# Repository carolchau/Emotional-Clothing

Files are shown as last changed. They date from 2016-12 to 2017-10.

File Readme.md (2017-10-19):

[emotions table]: http://i.imgur.com/i2DKPvF.png "Emotions Table"
[materials]: http://i.imgur.com/itTRcLl.jpg "Materials"
[wave shield]: http://i.imgur.com/GLxlWJJ.jpg "Wave Shield"
[rgb sensor]: http://i.imgur.com/IK1A827.jpg "RGB Sensor"
[lcd]: http://i.imgur.com/u8NLPdG.jpg "LCD"
[button]: http://i.imgur.com/u8NLPdG.jpg "Button"
[finished]: http://i.imgur.com/IV4h7Ai.jpg "Final Product"
[video]: http://i.imgur.com/NeDSLdI.jpg "Video"

# Emotional Clothing

Have you ever looked at someone's shirt and wondered, "What would that shirt sound like?". Of course you have.
Well now you can with this product. By simply hovering this device over someone's shirt or any article of clothing, you too can listen to the hidden melodies in our clothing.

We may not realize it but people often associate certain colors with specific feelings as numerous studies have shown. It's also no secret that music has incredible impact on our current state of emotions as well.
So why not combine these two factors to enhance the vibes they give off?

The colors and songs played will target emitting various emotions such as:

emotions table

## How it works

Every shirt will give off a specific HSL value. Based on that value, the device will play a specific song that will give off an atmospheric mood similar to what the color gives off. And LCD Screen will display the Song & Artist, the Mood, and the corresponding HSL value.

The HSL value that the sensor picks up will be classified into one of at least 8 ranges of colors. Depending on the range that HSL value falls under, it will play the corresponding song mapped to that range.

Because the color sensor I have will record RGB values, I will be using a formula to convert the RGB values into their corresponding HSL values.

This device is only intended to be used for solid colored shirts.

## Demo

[video](https://www.youtube.com/watch?v=GCqKvXHVLQU)

## Materials

materials

*Note*: Despite it being shown in most pictures, I will not be using the RGB LED due to compatibility issues and limited resources available to me given the devices I'm working with. I'm too lazy to resolder things and take the pictures again, so just pretend like the LED isn't there :)

## Assembly

### Construct the [Wave Shield](https://learn.adafruit.com/adafruit-wave-shield-audio-shield-for-arduino/overview)

wave shield

* This is probably the most difficult part of this project. Set aside an hour or two to solder this thing and put it together.
* I highly recommend you test out some songs before moving forward.

### Construct and Attach the [RGB Sensor](https://www.adafruit.com/product/1334)

rgb sensor

* This part is not difficult at all. Just make sure you read the instructions from Adafruit.
* Again, be sure to test this component individually.

### Attach the LCD Screen

lcd

* If you need help assembling this, you can refer to the schematic in this repository, or google your lcd model.

### Attach the button

button

* Again, this is fairly straight forward.
* You can't get much information about the wiring from the pictures anymore, so be sure to refer to the schematic.

## Final Product

finished

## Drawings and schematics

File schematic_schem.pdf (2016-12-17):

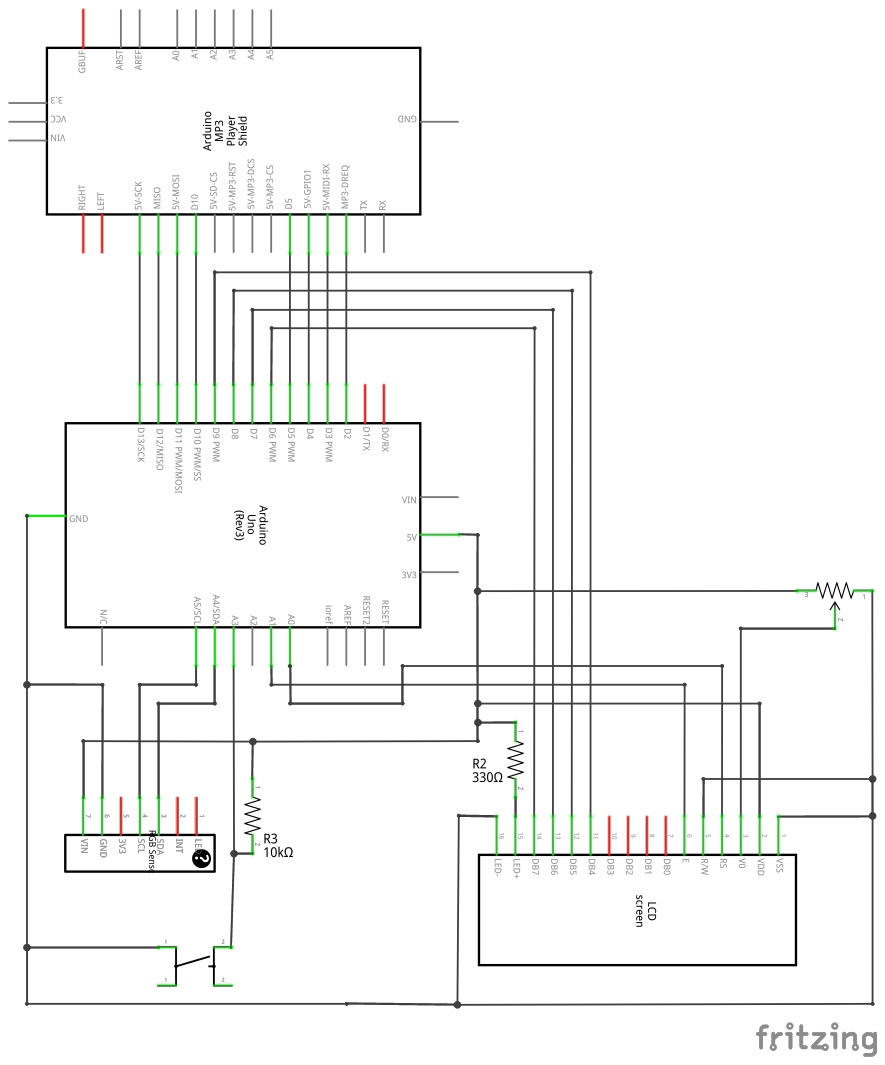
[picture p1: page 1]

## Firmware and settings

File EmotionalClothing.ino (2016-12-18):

/*
 * WaveHC and WaveUtil libraries are provided by Adafruit.
 * Source: https://github.com/adafruit/WaveHC
 *
 * RGB Color Sensor library (Adafruit_TCS34725) is also provided by Adafruit.
 * Source: https://github.com/adafruit/Adafruit_TCS34725
 */

#include <WaveHC.h>
#include <WaveUtil.h>
#include <Wire.h>
#include "Adafruit_TCS34725.h"
#include <LiquidCrystal.h>
#include "ColorUtil.h"

LiquidCrystal lcd(A0, A1, 9, 8, 7, 6);

const int button = A3;

SdReader card;    // This object holds the information for the card
FatVolume vol;    // This holds the information for the partition on the card
FatReader root;   // This holds the information for the volumes root directory
WaveHC wave;      // This is the only wave (audio) object, since we will only play one at a time

Adafruit_TCS34725 tcs = Adafruit_TCS34725(TCS34725_INTEGRATIONTIME_700MS, TCS34725_GAIN_1X);

void setupSdReader(SdReader &card) {
  if (!card.init()) Serial.println("Card init failed");
  card.partialBlockRead(true); // Optimization. Disable if having issues
}

void setupFatVolume(FatVolume &vol) {
  uint8_t slot;
  // There are 5 slots to look at.
  for (slot = 0; slot < 5; slot++)
    if (vol.init(card, slot)) break;
  if (slot == 5) Serial.println("No valid FAT partition");
}

void setupFatReader(FatReader &root) {
  if (!root.openRoot(vol)) Serial.println("Can't open root dir");
}

void setupRGBSensor(Adafruit_TCS34725 &tcs) {
  if (!tcs.begin()) Serial.println("No TCS34725 found ... check your connections");
}

void displayDirections() {
  lcd.begin(16, 2);
  lcd.clear();
  lcd.setCursor(0, 0);
  lcd.print("Hover clothing");
  lcd.setCursor(0, 1);
  lcd.print("over light.");
}

void setup() {
  Serial.begin(9600);
  setupSdReader(card);
  setupFatVolume(vol);
  setupFatReader(root);
  setupRGBSensor(tcs);
  displayDirections();
  pinMode(button, INPUT);
}

void play() {
  uint16_t clear, red, green, blue;

  tcs.setInterrupt(false);
  delay(60);
  tcs.getRawData(&red, &green, &blue, &clear);
  tcs.setInterrupt(true);

  uint32_t sum = clear;
  float r, g, b;
  r = red; r /= sum;
  g = green; g /= sum;
  b = blue; b /= sum;
  r *= 256; g *= 256; b *= 256;

  double hsl[3];
  getHSL(hsl, r, g, b);
//  Serial.print("r: "); Serial.print((int) r);
//  Serial.print(" g: "); Serial.print((int) g);
//  Serial.print(" b: "); Serial.print((int) b); Serial.println();
//  Serial.print("H: "); Serial.print(hsl[0]);
//  Serial.print(" S: "); Serial.print(hsl[1]);
//  Serial.print(" L: "); Serial.print(hsl[2]); Serial.println();

  int hue = hsl[0];
  double saturation = hsl[1];
  double light = hsl[2];

  lcd.begin(16, 2);
  lcd.clear();
  lcd.setCursor(0, 0); lcd.print('R'); lcd.print(r, 0);
  lcd.setCursor(5, 0); lcd.print('G'); lcd.print(g, 0);
  lcd.setCursor(10, 0); lcd.print('B'); lcd.print(b, 0);
  lcd.setCursor(0, 1); lcd.print('H'); lcd.print(hue);
  lcd.setCursor(5, 1); lcd.print('S'); lcd.print(saturation * 100, 0); lcd.print('%');
  lcd.setCursor(10, 1); lcd.print('L'); lcd.print(light * 100, 0); lcd.print('%');

  root.rewind();
  FatReader file;

  if (light < 0.2) {                // Black
    file.open(root, "gmechngd.wav");
  } else if (light > 0.8) {         // White
    file.open(root, "avemaria.wav");
  } else if (saturation < 0.05) {   // Gray
    file.open(root, "veridquo.wav");
  } else if (hue < 5) {            // Red
    file.open(root, "nitefate.wav");
  } else if (hue < 50) {            // Orange
    file.open(root, "mariothm.wav");
  } else if (hue < 110) {            // Yellow
    file.open(root, "wiishopc.wav");
  } else if (hue < 170) {           // Green
    file.open(root, "swedenmc.wav");
  } else if (hue < 230) {           // Blue
    file.open(root, "animcros.wav");
  } else if (hue < 360) {           // Magenta
    file.open(root, "wndrland.wav");
  }

  if (!wave.create(file)) Serial.println("Can't open the file");
  wave.play();
  while(wave.isplaying) delay(100);

  displayDirections();
}

void loop() {
  int state = digitalRead(button);
  bool pushed = (state == LOW);
  if (pushed) {
    play();
  }

  delay(50);
}

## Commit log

2016-11-19 Implement setup for RGB Color Sensor
2016-12-13 Fix LCD bug.
    Pins 11, 12, and 13 were being used by the Wave Shield, so I those pins
    needed to be used somewhere else. The only other place left for them
    were pins 1, and 0. Consequently, this removes the ability to use the
    Serial Monitor, which I am okay with.
    [EmotionalClothing.ino]
2016-12-14 Add button to only play when pressed
2016-12-14 Add schematic representation
    [schematic.fzz]
2016-12-17 Free up pin 1 and 0 after removing RGB LED
    Turns out I can't even use the RGB LED because it relies on a Soft Pulse
    With Modulation library which happens to be incompatible with the WaveHC
    library. This could be for the better since the RGB would have probably
    interfered with the actual color it was sensing.
    Actually, the RGB LED wouldn't have worked anyway with the Arduino even if
    the libraries were compatible. Using the LED would require a gammatable
    which is a byte array of size 256. That array with the WaveHC shield
    alone brings the global variable usage up to 96% of the limit.
    Attempting to add an additional library (SoftPWM) would have been
    impossible.
    [EmotionalClothing.ino]
2016-12-17 Add simple error message
    [EmotionalClothing.ino]
2016-12-17 Update schematic with removed RGB LED
    Also accurately depict the connections of the LCD.
    [schematic.fzz]
